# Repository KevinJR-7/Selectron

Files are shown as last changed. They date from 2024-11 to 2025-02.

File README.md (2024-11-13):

# Selectron
Maquina expendedora de dulces programada con raspberry pi pico
El sistema que implementaremos es una máquina expendedora de productos que no hemos definido. En esta
se ingresarán monedas de $500 y $1000 (COP) que serán detectadas con un sensor IR. Se seleccionará
mediante el sistema de pulsadores 2x2 el producto entre los 4 que estarán
disponibles y, según la validez de la selección y las monedas, cancelará la
compra(devolviendo lo ingresado), o entregará el producto junto a el dinero sobrante
haciendo el uso de servomotores. El sistema será alimentado con
considerable corriente y voltaje para los motores y será regulado para la
alimentación de la lógica. Además tanto el producto seleccionado, el dinero
ingresado y el estado de la compra se mostrarán en una pantalla.

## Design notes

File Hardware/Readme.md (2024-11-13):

# Hardware Selectron
En este subdirectorio irá todo lo relacionado al Hardware de la maquina Selectron.

El hardware de esta maquina se compone de el microcontrolador Raspberry Pi Pico. Este micro va a recibir y controlar multiples componentes, va a recibir la señal de 4 sensores infrarrojos para determinar las monedas que ingresen o si las ingresadas no corresponden a algun valor admitido además tendrá 4 botones para elegir entre 4 distintos productos, la elección de un producto u otro moverá uno de 4 distintos servomotores para desplazar el producto hacia el usuario, además tendrá una señal infrarroja mas para detectar la entrega o no de un producto. Por ultimo, tambien entregara la correcta devolucion del dinero según si el usuario ingresó mas de el valor del producto o si la compra es rechazada. Todo esto se verá reflejado en un display 16x2 que hará a su vez de interfaz con el usuario

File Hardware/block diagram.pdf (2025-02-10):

Diagrama de Bloques:

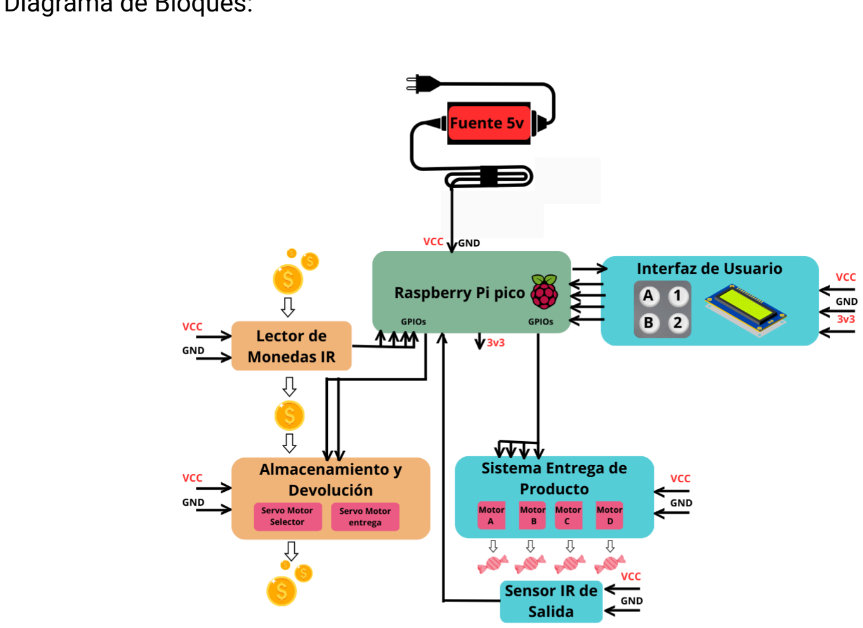
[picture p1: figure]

Explicación por partes:
-Fuente:
Fuente reutilizada de una consola de videojuegos portátil de 5V y 2A, esta provee de energía tanto al MCU como a cada módulo del proyecto.
-Raspberry Pi pico:
MCU utilizado para el montaje, recibe todas las señales censadas y entrega señales de control a los distintos módulos por medio de los gpio, además de proveer a los módulos que lo requieran una referencia de 3V.
-Lector de Monedas:
Pieza diseñada en 3D que consta de un camino por el cual se deslizan las monedas que entran en la máquina y un conjunto de 4 leds IR, con sus respectivos receptores a diferentes alturas, los cuales cumplen con la función de identificar la altura de la moneda (modelo disponible en el repositorio de Github).
-Almacenamiento de Monedas:
Para almacenar las monedas según su valor, se implementa un servomotor con una rampa que cambia la dirección de las monedas que salen de la etapa anterior hacia el tubo correspondiente a cada moneda (500, 1000, otras) (modelo disponible en el repositorio de Github).
-Devolución de Monedas:
Consta de un servomotor unido a un piñón con la mitad de sus dientes que mueve uno de los dos piñones cremallera que se ocupan de arrastrar la moneda más baja de la pila de monedas. Las monedas inferiores a los tamaños válidos se devuelven de forma inmediata (modelo disponible en el repositorio de Github).
-Interfaz:
Botones: Cuatro botones ubicados en la misma posición de los productos que puedes seleccionar con ellos.
Pantalla: Pantalla 16x2 lcd conectada a módulo I2C para mostrar información de la compra.
-Entrega de Productos:
Cuatro entradas rectangulares, cada una con un tornillo sin fin (con forma de resorte) unido a un sistema de poleas movido por medio de motores conectados a transistores que reciben señales PWM desde el MCU con el propósito de empujar los productos (Gráfica ilustrativa disponible en el repositorio de Github).
-Sensor de Salida:
Par emisor y receptor IR ubicados para detectar cuando un producto sale de su cabina y cae.

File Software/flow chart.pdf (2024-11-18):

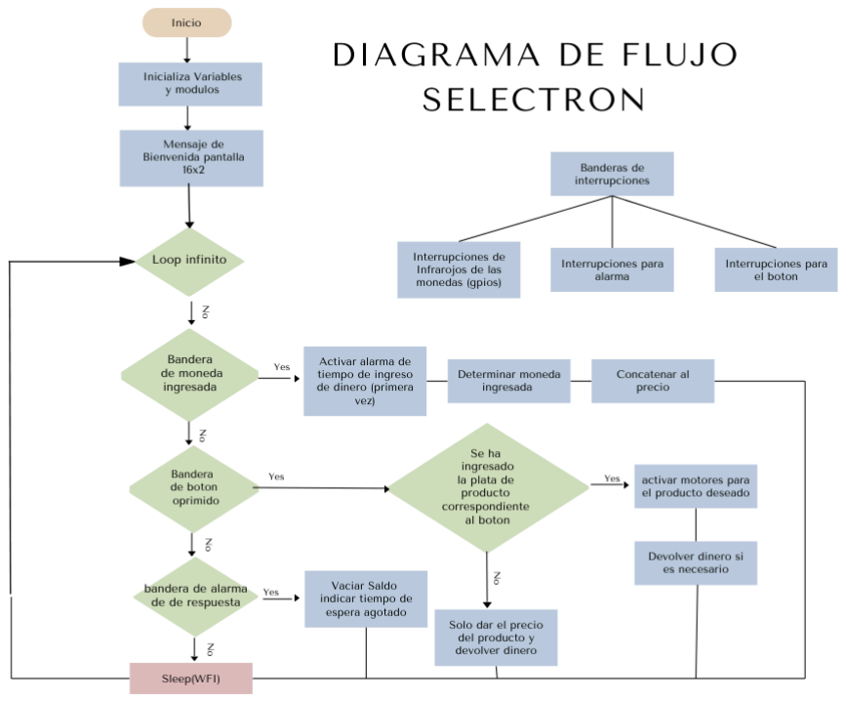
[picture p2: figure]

Para La implementación del código se quiere usar la estrategia del polling más interrupciones donde principalmente se va a tener interrupciones de gpios y alarmas. entonces gracias a los gpios podrán hacer lectura de los botones para cada producto y los leds infrarrojos serán usados para el caso de las monedas, están generan una interrupción donde se quiere leer que moneda es, para después sumarse al saldo, una vez hecho esto, el usuario presiona el botón del producto deseado y se hará la respectiva comparación para ver si el saldo concuerda con el precio del producto sino se le devolverá las monedas y se eliminará el valor del saldo, en caso contrario de activara los pwms para los motores y se le entregará el producto al usuario.

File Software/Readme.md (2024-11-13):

# Software Selectron
Se tiene un flujo de programa pensado de polling + interrupciones y se espera lograr el cometido

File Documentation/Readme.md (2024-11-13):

# Documentation Selectron
En esta carpeta irá toda la documentación que se irá recopilando para el funcionamiento de está máquina

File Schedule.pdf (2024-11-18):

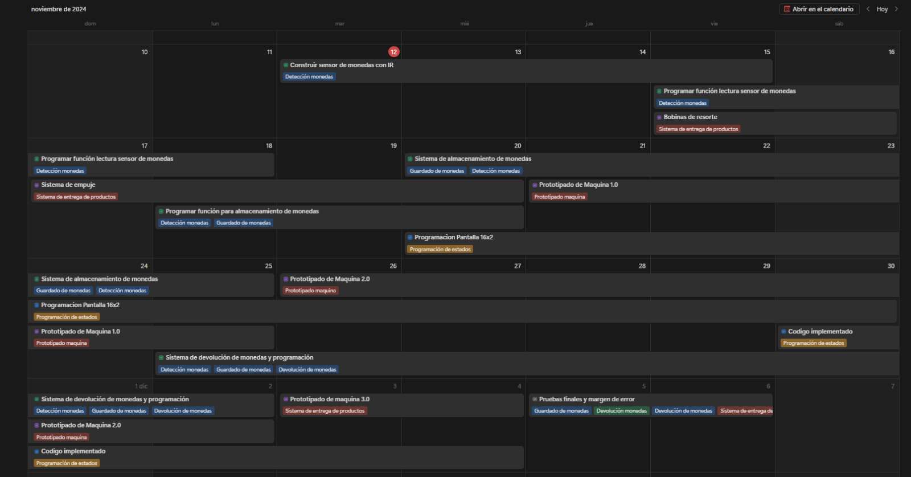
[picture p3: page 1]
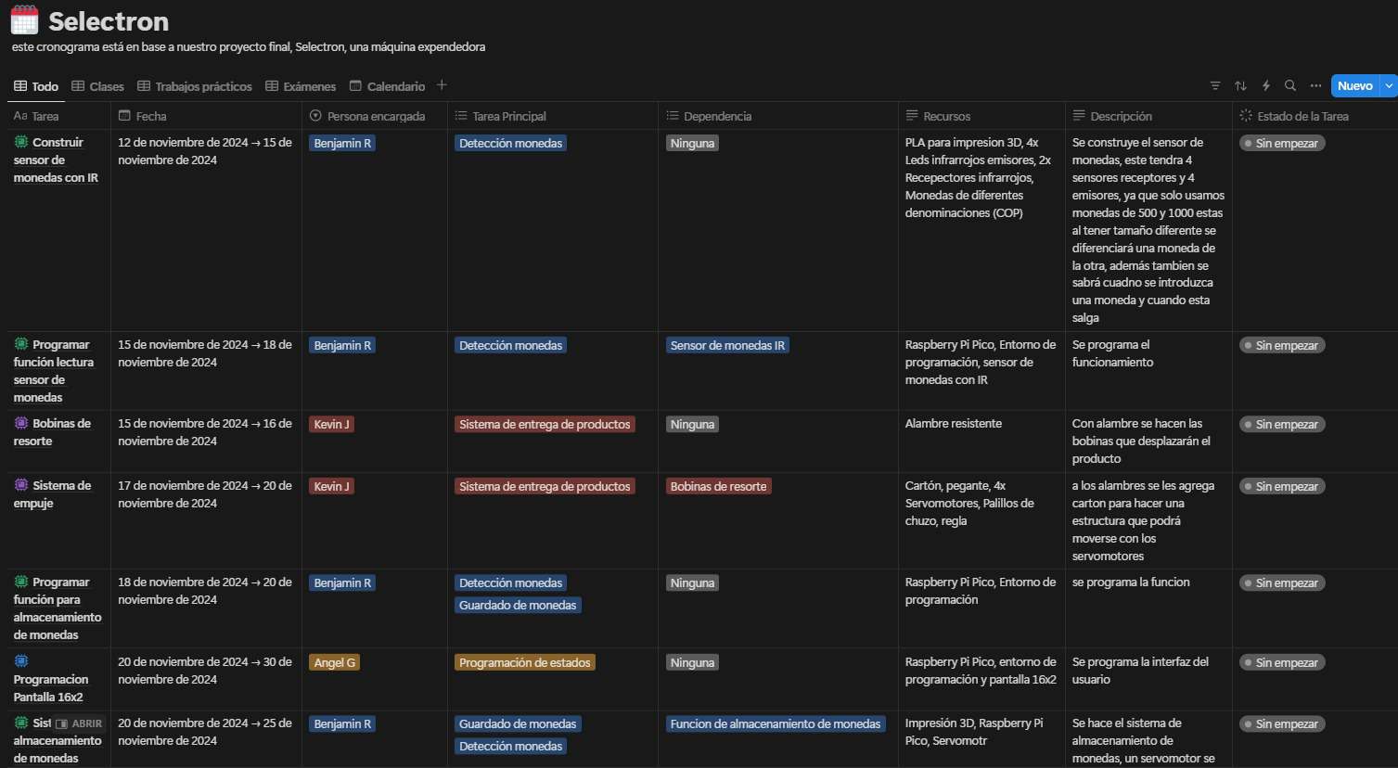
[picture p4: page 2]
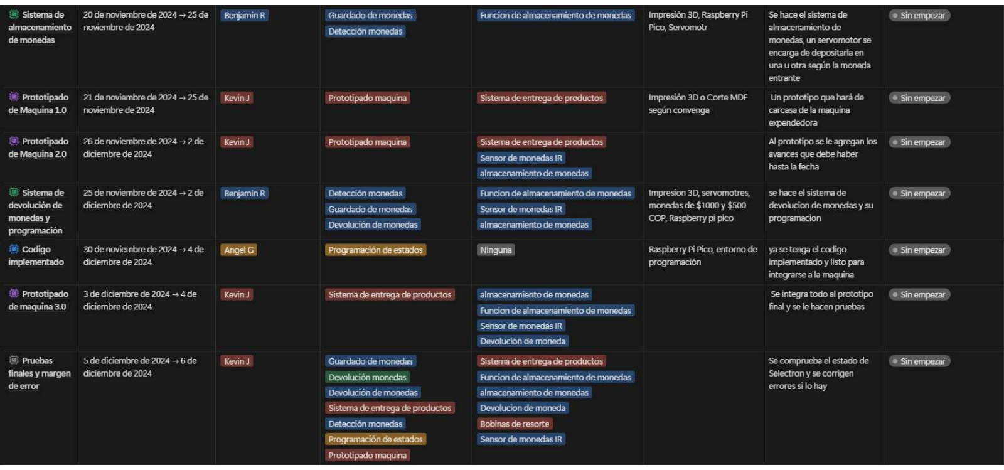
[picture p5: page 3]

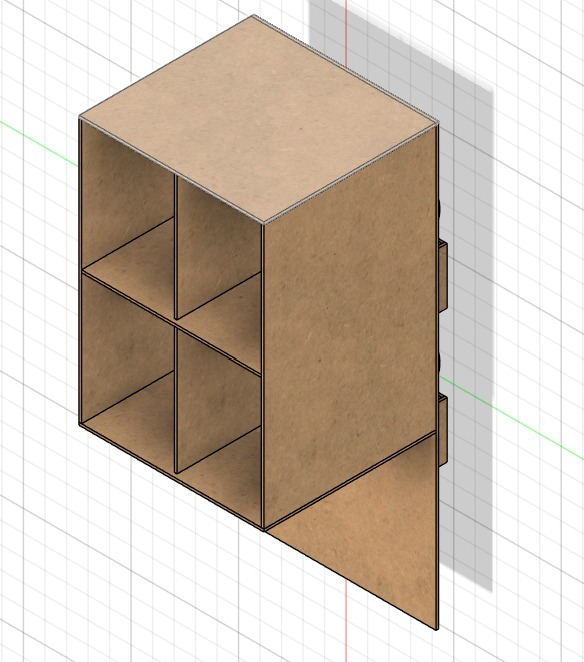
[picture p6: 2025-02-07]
Hardware/Dispensador de productos.jpg

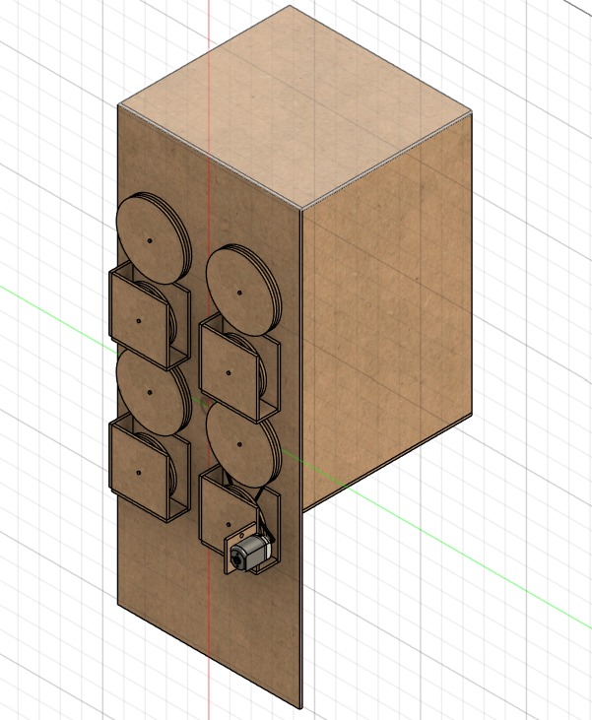
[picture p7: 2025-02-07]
Hardware/Dispensador de productos back.jpg

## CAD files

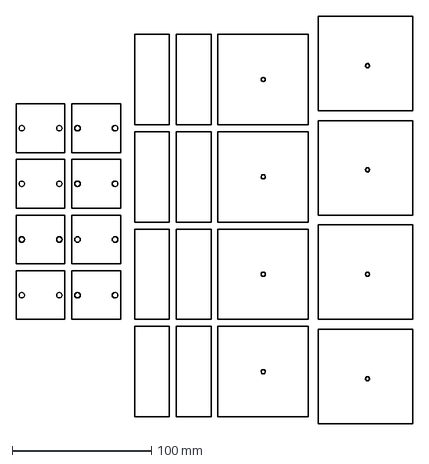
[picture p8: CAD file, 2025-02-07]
Hardware/Placas1.dxf
285.0 x 293.0 mm

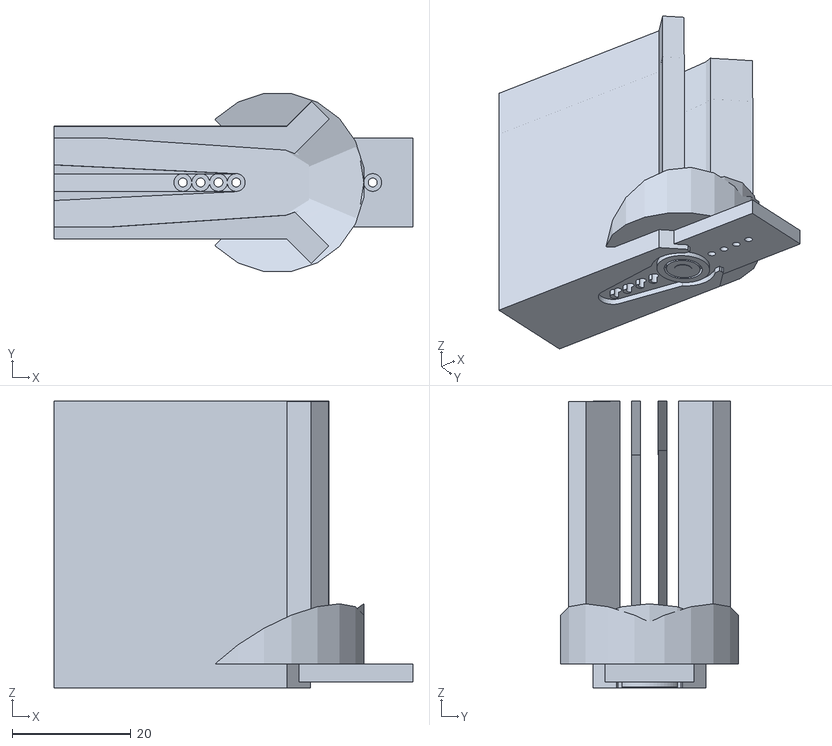
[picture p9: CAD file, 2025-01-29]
Software/Selector_de_monedas (2).stl
60.5 x 30.0 x 48.3

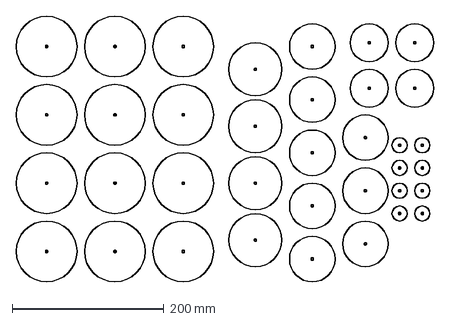
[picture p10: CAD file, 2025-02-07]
Hardware/Poleas.dxf
550.0 x 350.0 mm

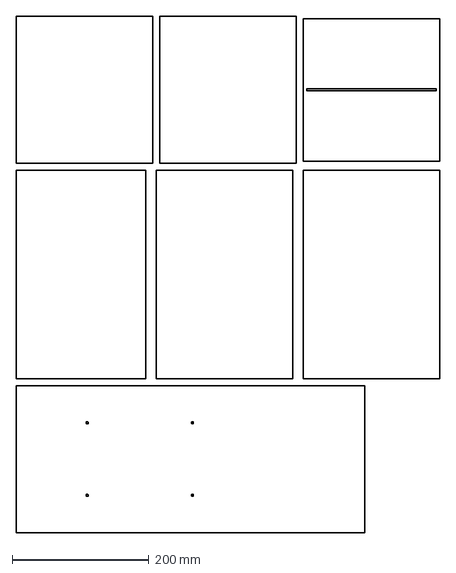
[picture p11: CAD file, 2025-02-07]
Hardware/Placas2.dxf
620.0 x 755.0 mm

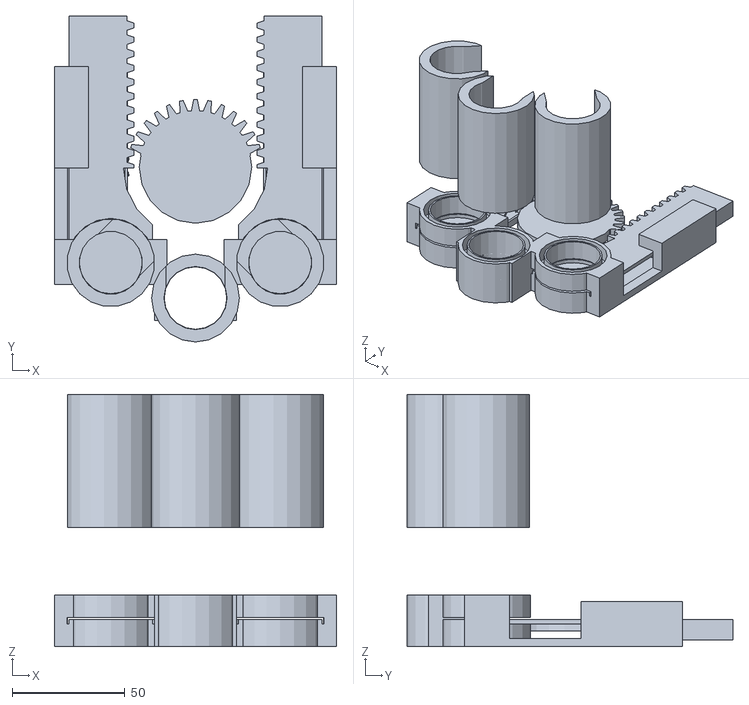
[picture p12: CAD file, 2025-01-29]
Hardware/dispensador_de_monedas.stl
125.2 x 144.7 x 112.0

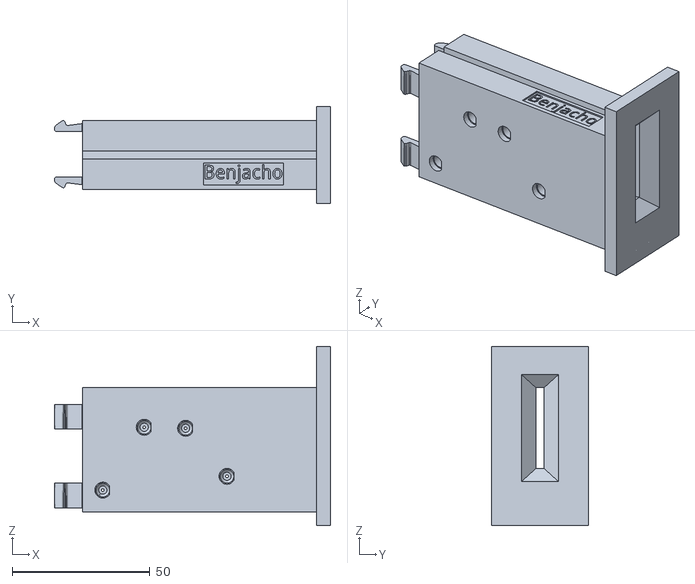
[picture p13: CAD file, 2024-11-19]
Hardware/Lector_de_monedas.stl
100.0 x 35.0 x 65.0

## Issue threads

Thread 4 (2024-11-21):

Cambiar la entrega de productos

KevinJR-7, 2024-11-21:
Pecamos de ignorancia y queriamos usar servomotores por el hecho de que eran sencillos de controlar su angulo sin hacer uso de tantos pines como un motor paso a paso, pero sucede que los servomotores son poco eficientes en giros de 360 grados, por lo cual debimos hacer uso de motorreductores dc normales, esto implica el uso de uno o mas puente H (aún en observación)

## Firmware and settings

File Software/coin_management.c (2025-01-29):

/**
 * @file coin_management.c
 * @brief Este documento contiene las funciones necesarias para la gestión de las monedas en la máquina expendedora.
 */

// Standard libraries
#include <stdio.h>
#include <math.h>
#include "pico/stdlib.h"
#include "hardware/pwm.h"
#include "hardware/clocks.h"
#include "hardware/gpio.h"

// Include your own header files here
#include "coin_management.h"

volatile uint8_t total_coin = 0;
uint8_t coin_1000_num = 2;
uint8_t coin_500_num = 2;
float top_g;
uint8_t servo_g;

//funcion para detectar el valor o validez de la moneda entrante
//esta funcion debe ser llamada al detectar un flanco de bajada en el IR de la entrada
uint8_t coin_ident(uint8_t c_500_gpio, uint8_t c_1000_gpio, uint8_t c_out_gpio)
{
    uint32_t cnt = 0;
    uint32_t c_500 = gpio_get(c_500_gpio);
    uint32_t c_1000 = gpio_get(c_1000_gpio);
    uint32_t c_out = gpio_get(c_out_gpio);
    while(c_500 && c_out)
    { 
        cnt += cnt; 
        c_500 = gpio_get(c_500_gpio);
        c_out = gpio_get(c_out_gpio);
        //if((cnt%125000000000) == 0){ printf("500: %d \n", c_500); printf("out: %d \n", c_out); }
    }
    if(!c_out){ return 0; } //retorno de 0 implica moneda invalida
    else
    {
        cnt = 0;
        c_1000 = gpio_get(c_1000_gpio);
        c_out = gpio_get(c_out_gpio);
        while(c_1000 && c_out)
        { 
            cnt += cnt; 
            c_1000 = gpio_get(c_1000_gpio);
            c_out = gpio_get(c_out_gpio);
        }

        if(!c_1000)
        { 
            total_coin += 5; 
            coin_500_num +=1;
            return 5; 
        } //retorno de 5 implica moneda de 500
        else
        { 
            total_coin += 10; 
            coin_1000_num +=1;
            return 10; 
        }  //retorno de 10 implica moneda de 1000
    }
}

//funcion para calcular la devuelta
//price es 5-10-15-etc
int8_t coin_change(uint8_t price)
{
    int8_t change = -1;
    if(price <= total_coin)    //revisa que no falte plata del usuario
    {
        change = total_coin - price;
        if(change > ((coin_1000_num*10) + (coin_500_num*5)))     //revisa que no falte plata en la máquina
        {
            return -2;  //cambio insuficiente
        }
        else if(((change%10) > 0) && (coin_500_num < 1))
        {
            return -3;  //insuficientes monedas de 500 (cambio no exacto)
        }
    }
    return change;
}

//funcion para entregar la devuelta
//calcula la mejor forma de entregar la devuelta teniendo en cuenta las monedas disponibles
void coin_change_deliver(uint8_t change, float top)
{
    total_coin = 0;
    uint8_t change_10 = change/10;
    uint8_t change_5 = (change%10)/5;
    if(change_10 > coin_1000_num)   //revisa si hay suficientes de 1000
    {
        change_5 += (change_10-coin_1000_num)*2;
        change_10 = coin_1000_num;
    }
    printf("change_5: %d \n", change_5);
    printf("change_10: %d \n", change_10);
    while(change_10 > 0)
    {
        sleep_ms(2000);
        coin_way(SERVO2_PIN, 10, top);
        change_10 -= 1;
        coin_1000_num -= 1;
        printf("change_10: %d \n", change_10);
    }
    while(change_5 > 0)
    {
        sleep_ms(2000);
        coin_way(SERVO2_PIN, 5, top);
        change_5 -= 1;
        coin_500_num -= 1;
        printf("change_5: %d \n", change_5);
    }
}

//funcion para cambiar el camino por el que se dijiren las monedas
//inicialmente esta funcion tambien puede ser llamada para el motor de la devuelta
void coin_way(uint8_t servo_gpio, uint8_t coin_case, float top)
{
    top_g = top;
    float fix;
    int ang;
    uint32_t back_ms;
    if(servo_gpio == SERVO1_PIN)
    {
        fix = 35;
        ang = 50;
        back_ms = 200;
        servo_g = servo_gpio;
    }
    else if(servo_gpio == SERVO2_PIN)
    {
        fix = 37;
        ang = -55;
        back_ms = 1000;
        servo_g = servo_gpio;
    }               else{fix = 0; ang = 0;}
    float duty_cycle;
    switch(coin_case) 
    { 
        case 0: 
        duty_cycle = angle_to_duty(90, fix);
        break;

        case 5: 
        duty_cycle = angle_to_duty(90-ang, fix);//145
        add_alarm_in_ms(back_ms, come_back_irq, NULL, true);
        break;

        case 10: 
        duty_cycle = angle_to_duty(90+ang, fix);//35
        add_alarm_in_ms(back_ms, come_back_irq, NULL, true);
        break;

        default: 
        duty_cycle = angle_to_duty(90, fix);
        break;
    }
    pwm_set_gpio_level(servo_gpio, top * duty_cycle);
}

// Calcula el ciclo de trabajo para el ángulo deseado 
float angle_to_duty(float angle, float fix)
{ 
    float pulse_width_us = 1000.f + ((angle-fix) * 1000.f / 93.f); // 1000 us para 0 grados, 2000 us para 180 grados 
    float duty_cycle = (pulse_width_us / 20000.f) ; // Convertir a duty cycle de PWM 
    return duty_cycle;
}

//Inicializa el PWM para el gpio deseado
float servo_pwm_init(uint8_t servo_gpio)
{
    // Configura el pin GPIO para PWM 
    gpio_set_function(servo_gpio, GPIO_FUNC_PWM); 
    uint slice_num = pwm_gpio_to_slice_num(servo_gpio); 
    /* // Configura el valor de wrap para un período de 20ms 
    uint32_t freq = 50; // frecuencia
    uint32_t clock_freq = clock_get_hz(clk_sys); // Frecuencia del reloj del sistema
    uint16_t top = clock_freq / freq - 1;
    pwm_set_wrap(slice_num, top);
    // Habilita el PWM 
    pwm_set_enabled(slice_num, true); */

    

    float clockDiv = 64;
    float wrap = 39062; 
    pwm_config config = pwm_get_default_config();
    
    uint64_t clockspeed = clock_get_hz(5);

    while (clockspeed/clockDiv/50 > 65535 && clockDiv < 256) clockDiv += 64; 
    wrap = clockspeed/clockDiv/50;

    pwm_config_set_clkdiv(&config, clockDiv);
    pwm_config_set_wrap(&config, wrap);

    pwm_init(slice_num, &config, true);

    return wrap;
}

int64_t come_back_irq(alarm_id_t id, void *top1) 
{ 
    //flag_alarm = 1;
    /* float *top2 = (float *)top1;
    float top = *top2; */
    coin_way(servo_g, 0, top_g);
    return 0; // No se repite la alarma
}

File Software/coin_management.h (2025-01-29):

/**
 * @file main.h
 * @brief This is a brief description of the main H file.
 *
 * Detailed description of the main C file.
 */
 
// Avoid duplication in code
#ifndef _COIN_H_
#define _COIN_H_

// Write your definitions and other macros here

#define SERVO1_PIN  15
#define SERVO2_PIN  16

#define C_IN_PIN    19
#define C_500_PIN   18
#define C_1000_PIN  20
#define C_OUT_PIN   21

uint8_t coin_ident(uint8_t, uint8_t, uint8_t);
void coin_way(uint8_t, uint8_t, float);
float angle_to_duty(float, float);
float servo_pwm_init(uint8_t);
int8_t coin_change(uint8_t);
void coin_change_deliver(uint8_t, float);
int64_t come_back_irq(alarm_id_t, void *);


#endif

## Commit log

2024-11-18 Add files via upload
    flow chart and description
2024-11-19 Modelo 3D del lector de monedas
    Modelo 3D diseñado en tinkercad con todo lo necesario para ser usado en el lector de monedas de nuestro proyecto. Incluye espacio para Sensores IR, abertura para moneda, rampa para el desplazamiento 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
    [Lector_de_monedas.stl]
2024-11-21 Códigos Gestión de Monedas
    Archivos .c y .h necesarios para uso de las funciones que detectan el valor de las monedas y cambian el camino de las monedas para su almacenamiento o devolución.
2025-01-29 Actualizacion 2
    Errores en versiones anteriores arreglados y funciones para la entrega de cambio agregadas
    [coin_management.c, coin_management.h]
2025-01-29 Modelo 3D selector de monedas
    luego de pasar por el sensor, la moneda es dirigida hacia alguno de los 3 tubos con la ayuda de un servomotor y esta pieza, la cual va atornilladas al servo.
    [Selector_de_monedas (2).stl]
2025-01-29 Dispensador de Monedas
    el engrane del centro va unido a un servomotor que gira hacia los lados para empujar las monedas de la base de la torre hacia afuera o dejar pasar las monedas derecho hacia afuera.
    [dispensador_de_monedas.stl]
2025-02-07 Add files via upload
    Se hace el modelo 3D de lo que se tiene pensado para el dispensador de productos con gran inspiración en el video citado en "Documentation" y se imprime en mdf en los .jpg se puede ver el diseño
    [Placas1.dxf, Placas2.dxf, Poleas.dxf]
